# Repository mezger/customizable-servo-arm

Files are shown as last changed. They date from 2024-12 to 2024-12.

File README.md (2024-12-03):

# customizable-servo-arm
A customizable servo-arm generator in OpenSCAD for generating servo-arm models for 3D-printing

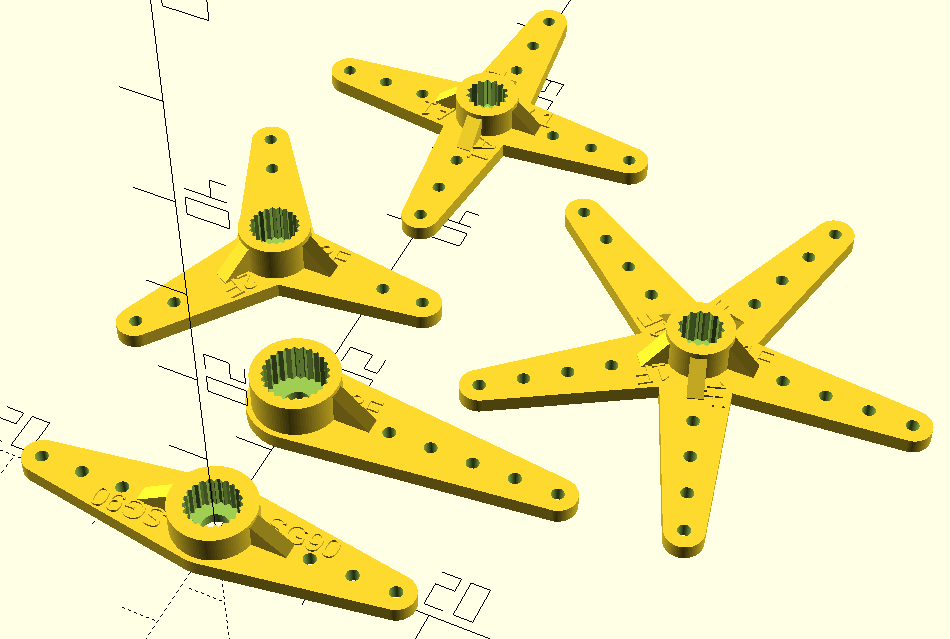
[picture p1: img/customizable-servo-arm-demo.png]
Demo


## Description

A customizable OpenSCAD model to generate a servo arm that exactly fits your needs.

It is based on the work by [Paul Barrett](https://github.com/hugokernel/OpenSCAD_ServoArms) and [Charles Rincheval](https://www.thingiverse.com/thing:630862). I added the splines for SG90, SG90TP and HITEC A1 servos, and reworked the layout of arm and support.

## Usage

In OpenSCAD select the desired parameters in the customizer window. If the customizer window is not visible, enable it by unslecting *Window* -> *Hide Customizer*.

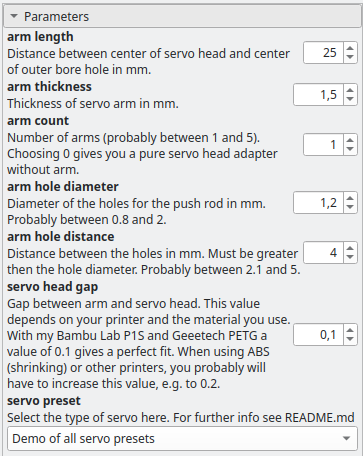
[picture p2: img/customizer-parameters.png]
Customizer


Then render the servo arm and export as STL.

## Parameters

### arm length

Regular servo arms usually have a distance between center of servo head and center of outer bore hole of about 25mm to 30mm, arms for micro servos have 14.8mm.

### arm thickness

Regular servo arms usually have a thickness of 2mm, arms for micro servos have 1.5mm.

### arm count

Number of arms, probably between 1 and 5. Choosing 0 gives you a pure servo head adapter without arm.

### arm hole diameter

Regular servo arms usually have a hole diameter of 1.5mm, arms for micro servos have 0.9mm. You can adjust this to fit the diameter of your push rod. 

### arm hole distance

Regular servo arms usually have a hole distance of 5mm, arms for micro servos have 2.1mm.

### servo head gap

The gap between arm and servo head. This value depends on your printer and the material you use. With my Bambu Lab P1S and Geeetech PETG filament, a value of 0.1 gives a perfect fit. When using ABS (shrinking) or not-so-well-fine-tuned printers, you probably will have to increase this value.

## Servo splines

The Futaba 3F spline is the most common spline for standard servos. It fits a large variety of servos and brands.

For the 9g micro servos called SG90, I learned that there exist at least two different sizes of the servo head. A Tower Pro SG90 servo has a smaller diameter of the servo head then all the other NoName SG90 servos I own. So I designed splines for both sizes, called SG90 for the bigger NoName (4.9mm diameter) and SG90TP for the smaller sized Tower Pro (4.7mm diameter) variant.

### Futaba 3F (25 teeth)

This is the most commonly used servo spline for "standard" servos. Futaba 3F is identical to Hitec H25T.

* MG 996R

### Futaba 2F (21 teeth)

Micro servos like S3153, S3107, S117

* Futaba S3153 MG Digital
* Futaba S3107 Nano
* Turnigy TG9e

### Futaba 1F (15 teeth)

* ???

### HITEC A1 aka. A15T (15 teeth)

* ???

### SG90 (21 teeth)

This is for Micro Servos like the NoName SG90 9g Micro Servo.

### SG90TP (21 teeth)

This is for Micro Servos like the Tower Pro SG90 9g Micro Servo or Tower Pro MG90S Micro Servo (with metal gear).

## Further info

Some useful information about servo splines is found here:

* [ServoCity Glossary - Servo Splines](https://www.servocity.com/glossary#servo-splines)
* [Servo Spline Info](https://www.hepf.at/servo-spline-information/) (german)
* [Servo Horn Arm Spline Count and Inter Brand Compatibility](https://www.rcgroups.com/forums/showpost.php?p=13441675)
* [RC Servo Spline Chart](https://www.robotdigg.com/news/168/RC-Servo-Spline-Chart)

There seems to be no real specification for SG90 servo splines available, so some people tried to reverse engineer this spline:

* [Modelling a Servo Spline](https://community.robotshop.com/blog/show/modelling-a-servo-spline)
* [Spline Thieving Makes Hobby Servos Even More Useful](https://hackaday.com/2015/02/01/spline-thieving-makes-hobby-servos-even-more-useful/)
* [Servo Spline Adapters](http://projectsbyjb.blogspot.com/2014/11/servo-spline-adapters.html)

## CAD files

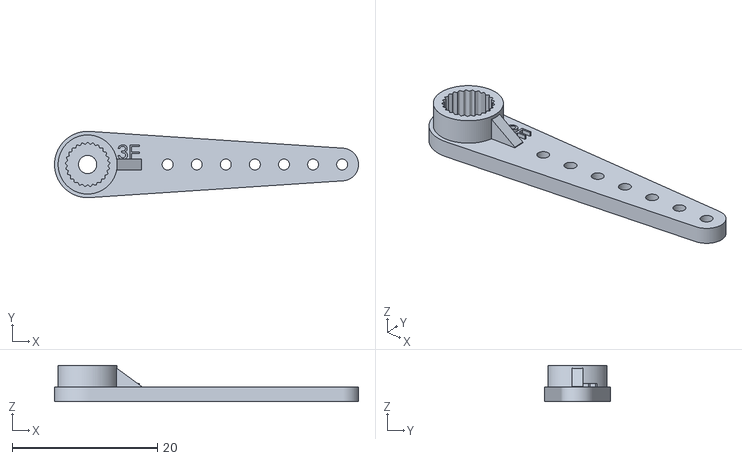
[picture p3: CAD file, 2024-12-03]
stl/customizable-servo-arm-35-2.0-1-1.5-4-0.1-3F.stl
41.8 x 9.12 x 5.00

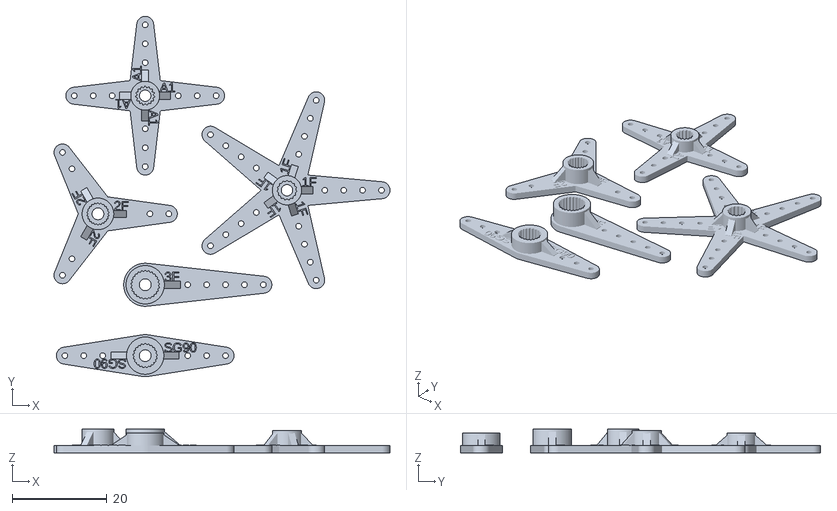
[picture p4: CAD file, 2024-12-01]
stl/customizable-servo-arm-demo.stl
71.1 x 76.3 x 5.00

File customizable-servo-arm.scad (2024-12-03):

/**
 *  Customizable servo arm generator for OpenSCAD by Matthias Mezger
 *
 *  Based on "Parametric Servo Arms 3F 2F 1F" by Paul Barrett (https://www.thingiverse.com/thing:630862)
 *  and "Parametric servo arms" by Charles Rincheval (https://www.thingiverse.com/thing:28566)
 *
 *  Info:
 *  https://www.hepf.at/servo-spline-information/
 *  https://community.robotshop.com/blog/show/modelling-a-servo-spline
 *  http://projectsbyjb.blogspot.com/2014/11/servo-spline-adapters.html
 *
 *
 *  This library is free software; you can redistribute it and/or
 *  modify it under the terms of the GNU Lesser General Public
 *  License as published by the Free Software Foundation; either
 *  version 2.1 of the License, or (at your option) any later version.
 *
 *  This library is distributed in the hope that it will be useful,
 *  but WITHOUT ANY WARRANTY; without even the implied warranty of
 *  MERCHANTABILITY or FITNESS FOR A PARTICULAR PURPOSE.  See the GNU
 *  Lesser General Public License for more details.
 *
 *  You should have received a copy of the GNU Lesser General Public
 *  License along with this library; if not, write to the Free Software
 *  Foundation, Inc., 51 Franklin St, Fifth Floor, Boston, MA  02110-1301  USA
 */


// Distance between center of servo head and center of outer bore hole in mm.
arm_length = 25;

// Thickness of servo arm in mm.
arm_thickness = 2;

// Number of arms (probably between 1 and 5). Choosing 0 gives you a pure servo head adapter without arm.
arm_count = 1;

// Diameter of the holes for the push rod in mm. Probably between 0.8 and 2.
arm_hole_diameter = 1.5;

// Distance between the holes in mm. Must be greater then the hole diameter. Probably between 2.1 and 5.
arm_hole_distance = 4;

// Gap between arm and servo head. This value depends on your printer and the material you use. With my Bambu Lab P1S and Geeetech PETG a value of 0.1 gives a perfect fit. When using ABS (shrinking) or other printers, you probably will have to increase this value, e.g. to 0.2.
servo_head_gap = 0.1;

// Select the type of servo here. For further info see README.md
servo_preset="3F"; // [3F:FUTABA 3F Standard Spline (25T), 2F:FUTABA 2F Spline (21T), 1F:FUTABA 1F Spline (15T), A1:HITEC A1 Sub-micro Spline (15T), SG90:NoName SG90 9g Micro Servo Spline (21T), SG90TP:Tower Pro SG90 9g Micro Servo Spline (21T),  DMO:Demo of all servo presets]


/* [Hidden] */

$fn = 100;

/**
 *  Head / Tooth parameters
 *
 *  First array (head related) :
 *  0. Head external diameter (including teeth)
 *  1. Head heigth
 *  2. Head thickness (thickness of wall)
 *  3. Head screw diameter (diameter of screw hole)
 *
 *  Second array (tooth related) :
 *  0. Tooth count
 *  1. Tooth height
 *  2. Tooth length
 *  3. Tooth width
 */
// FUTABA 3F Standard Spline (25 teeth)
FUTABA_3F_SPLINE = [
    [5.92, 4, 1.1, 2.5],
    [25, 0.3, 0.7, 0.1]
];
// FUTABA 2F Spline (21 teeth) ??
FUTABA_2F_SPLINE = [
    [4.5, 4, 1.1, 2.5],
    [22, 0.25, 0.6, 0.09]
];
// FUTABA 1F Spline (15 teeth)
FUTABA_1F_SPLINE = [
    [4.0, 3.75, 1.1, 2.4],
    [15, 0.25, 0.6, 0.09]
];
// HITEC A1 Sub-micro Spline (15 teeth)
// A15T = A1 3.9mm
A15T_A1_SPLINE = [
    [3.9, 3.2, 1.1, 2.4],
    [15, 0.375, 0.66, 0.13]
];
// SG90 21T (approximation, because the SG90 has a round tooth profile, see  https://community.robotshop.com/blog/show/modelling-a-servo-spline)
SG90_SPLINE = [
    [4.9, 3.2, 1.5, 2.5],
    [21, 0.25, 0.65, 0.25]
];
// Tower Pro SG90 21T 
SG90TP_SPLINE = [
    [4.7, 3.2, 1.5, 2.5],
    [21, 0.25, 0.65, 0.25]
];
// HITEC B1 Mini Spline (25 teeth) -> TODO
// HITEC C1 Standard Spline (24 teeth) -> TODO
// HITEC H25T Hitec Standard Spline (25 teeth) -> identical to FUTABA 3F
// HITEC D1 Heavy Duty Spline (15 teeth) -> TODO
// JR Graupner 23T (23 teeth) -> TODO
// Robbe: 25T ???
// Towerpro Micro 20T ???
// Traxxas: 25T ???


/**
 *  servo head tooth
 *
 *    |<-w->|
 *    |_____|___
 *    /     \  ^h
 *  _/       \_v
 *   |<--l-->|
 *
 *  - tooth length (l)
 *  - tooth width (w)
 *  - tooth height (h)
 *  - height
 *
 */
module servo_head_tooth(length, width, height, head_height) {
    linear_extrude(height = head_height) {
        polygon([[-length / 2, 0], [-width / 2, height], [width / 2, height], [length / 2,0]]);
    }
}


/**
 *  Servo head (a model of the part where our servo arm will fit on) 
 *  This will later be subtracted from our arm.
 */
module servo_head(params, gap = servo_head_gap) {

    head = params[0];
    tooth = params[1];

    head_diameter = head[0];
    head_heigth = head[1];

    tooth_count = tooth[0];
    tooth_height = tooth[1];
    tooth_length = tooth[2];
    tooth_width = tooth[3];

    //% cylinder(r = head_diameter / 2, h = head_heigth + 1);

    //the core of the head
    cylinder(r = head_diameter/2 - tooth_height + 0.03 + gap, h = head_heigth);

    //the teeth
    for (i = [0 : tooth_count]) {
        rotate([0, 0, i * (360 / tooth_count)]) {
            translate([0, head_diameter/2 - tooth_height + gap, 0]) {
                servo_head_tooth(tooth_length, tooth_width, tooth_height, head_heigth);
            }
        }
    }
}


/**
 *  Servo adapter (the part that fits on the servo head). This is the base for our servo arm,
 *  and it can be the base for other parts that are directly mounted on an servo.
 */
module servo_adapter(params, gap = servo_head_gap) {
    head = params[0];
    tooth = params[1];

    head_diameter = head[0];
    head_heigth = head[1];
    head_thickness = head[2];
    head_screw_diameter = head[3];

    tooth_length = tooth[2];
    tooth_width = tooth[3];

    difference() {
        cylinder(r = head_diameter/2 + head_thickness, h = head_heigth + 1);
        cylinder(r = head_screw_diameter/2, h = head_heigth + 1);
        translate([0,0,1]) servo_head(params, gap);
    }
}


/**
 *  Servo arm
 */
module servo_arm(params, gap = servo_head_gap, preset = servo_preset, arm_count = arm_count, arm_length = arm_length) {
    head = params[0];
    tooth = params[1];

    head_diameter = head[0];
    head_heigth = head[1];
    head_thickness = head[2];
    head_screw_diameter = head[3];

    if(arm_count > 0)
    {
        for(i=[0:360/arm_count:360]) {
            rotate([0,0,i]) {
                difference() {
                    hull() {
                        cylinder(r = head_diameter/2 + head_thickness + 0.5, h = arm_thickness);
                        translate([arm_length,0,0]) cylinder(d=3*arm_hole_diameter, h=arm_thickness);
                    }
                    //cut-out for servo_adapter
                    cylinder(r = head_diameter/2 + head_thickness - 0.1, h = arm_thickness);
                    //holes
                    hole_count = (arm_length-(head_diameter/2+head_thickness+head_heigth))/arm_hole_distance;
                    for(j=[0:hole_count]) {
                        translate([arm_length-j*arm_hole_distance,0,0]) 
                            cylinder(d=arm_hole_diameter, h=arm_thickness);
                    }
                }
                //support
                translate([head_diameter/2+head_thickness-0.7,-0.75,arm_thickness]) hull() {
                    cube([head_diameter/2 + head_thickness, 1.5, 0.1]); 
                    cube([0.1, 1.5, head_heigth+1-arm_thickness]); 
                }
                //text
                translate([head_diameter/2+head_thickness,0.75,arm_thickness]) 
                        linear_extrude(0.5) text(text=preset,size=2);
            }
        }
    }
    //servo adapter in the middle
    servo_adapter(params, gap);
}


if(servo_preset=="3F") servo_arm(FUTABA_3F_SPLINE, servo_head_gap);
if(servo_preset=="2F") servo_arm(FUTABA_2F_SPLINE, servo_head_gap);
if(servo_preset=="1F") servo_arm(FUTABA_1F_SPLINE, servo_head_gap);
if(servo_preset=="A1") servo_arm(A15T_A1_SPLINE, servo_head_gap);
if(servo_preset=="SG90") servo_arm(SG90_SPLINE, servo_head_gap);
if(servo_preset=="SG90TP") servo_arm(SG90TP_SPLINE, servo_head_gap);
if(servo_preset=="DMO") {
    translate([0,15,0]) servo_arm(FUTABA_3F_SPLINE, servo_head_gap, "3F", 1, 25);
    translate([-10,30,0]) servo_arm(FUTABA_2F_SPLINE, servo_head_gap, "2F", 3, 15);
    translate([30,35,0]) servo_arm(FUTABA_1F_SPLINE, servo_head_gap, "1F", 5, 20);
    translate([0,55,0]) servo_arm(A15T_A1_SPLINE, servo_head_gap, "A1", 4, 15);
    translate([0,0,0]) servo_arm(SG90_SPLINE, servo_head_gap, "SG90", 2, 17);
}



//servo_head(SG90_SPLINE, 0);
//servo_adapter(SG90_SPLINE);
//servo_arm(SG90_SPLINE, servo_head_gap);

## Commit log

2024-12-01 initial checkin
    [customizable-servo-arm.scad]
2024-12-01 parameters and description
    [customizable-servo-arm.scad]
2024-12-01 text on top and bottom
    [customizable-servo-arm.scad]
2024-12-01 text only on bottom
    [customizable-servo-arm.scad]
2024-12-01 added demo mode
    [customizable-servo-arm.scad]
2024-12-01 README.md, images, stl
    [customizable-servo-arm-demo.stl, customizable-servo-arm.scad]
2024-12-03 added SG90TP and STL for 3F standard arm
    [customizable-servo-arm-35-2.0-1-1.5-4-0.1-3F.stl, customizable-servo-arm.scad]
